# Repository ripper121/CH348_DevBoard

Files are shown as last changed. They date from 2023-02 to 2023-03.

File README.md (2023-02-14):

# CH348 DevBoard
### USB to Octal Serial / Uart ports

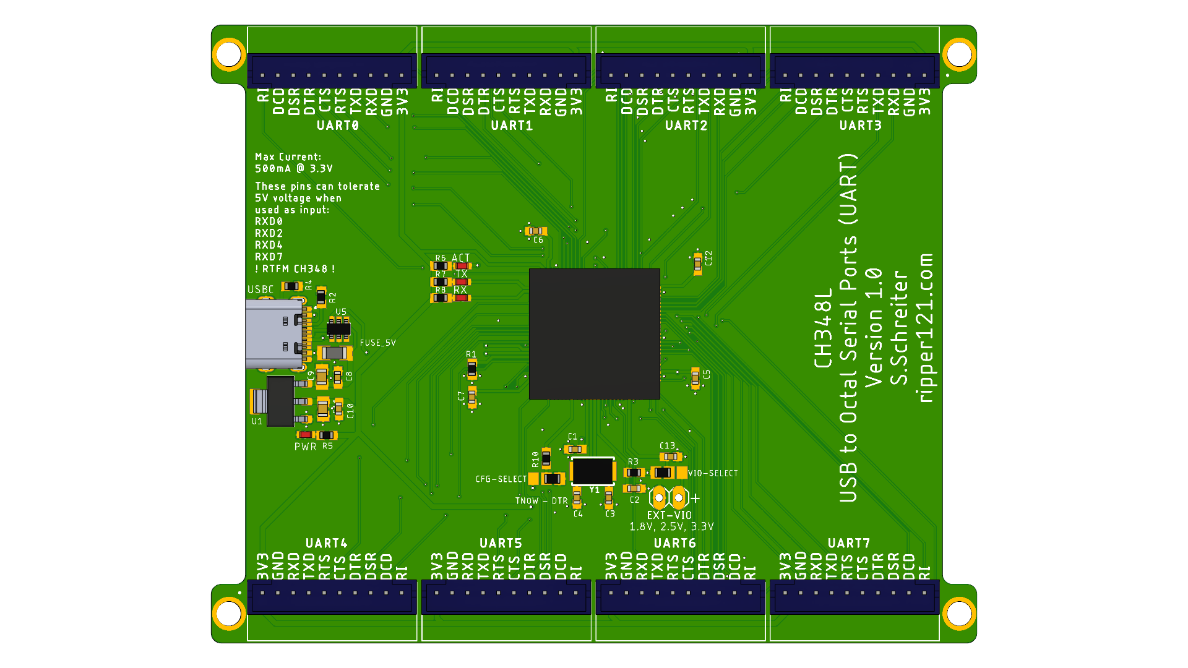
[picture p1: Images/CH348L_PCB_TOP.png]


### Features:
- No drivers needed for Winows and Linux
- USB-C Connector
- USB ESD Protection
- 500mA Polyfuse (self resettable fuse)
- Leds:
 - RX shows data receiving status
 - TX shows data transmitting status
 - ACT shows USB configuration completed status
- Jumpers
 - CFG: During power-on, if the CFG pin is
at a high level or not connected, all DTRx/ TNOWx pins
are configured to function as TNOW. CFG pin is low, all
DTRx/ TNOWx pins are configured for DTR function.
- VIO: The power supply of RTS0, CTS0, DTR4, DTR5, DTR6 and DTR7 pins of CH348L come from VCC,
these pins are 3.3V signal level. The power supply of other UARTs and MODEM signal pins come
from VIO, which are 3.3V/2.5V/1.8V matching VIO signal level.
- JST PH 2.0mm 10 Pin Connectors for the UART Pins
 - 3V3, GND, RXD, TXD, RTS, CTS, DTR, DSR, DCD, RI
- Size 100 x 80 mm
- 3.2 mm mounting holes

###### From Datasheet:
- 480Mbps high-speed USB device interface, peripheral components only need crystal oscillator and capacitors
- Built-in firmware, emulate standard UART interface, used to upgrade the original serial peripheral or expand additional UART via USB
- Original serial applications are totally compatible without any modification in Windows operating systems
- Hardware full duplex UART interface, integrated independent transmit-receive buffer, supports communication baud rate varies from 1200bps to 6Mbps
- UART supports 8 data bits, supports odd, even, and none parity, supports 1 or 2 stop bits
- Integrated the 2048-byte RX FIFO and 1024-byte TX FIFO for each UART
- Supports common MODEM signals RTS, DTR, DCD, RI, DSR and CTS
- Supports CTS and RTS hardware automatic flow control
- Supports half-duplex, provides sending status TNOW, used for controlling RS485 to transmit-receive switch
- Supports up to 48-channel GPIO input and output function
- Supports RS232/RS485/RS422 interface, through external voltage conversion chip
- Built-in EEPROM used to configure the chip of VID, PID, maximum current value, vendor and product information string, etc

[CH348 Datasheet](https://github.com/ripper121/CH348_DevBoard/raw/main/Datasheets/CH348DS1.PDF "CH348 Datasheet")

[Driver & Software](http://www.wch-ic.com/search?q=CH348&t=downloads "Driver & Software")

If you want to order one assembled PCB: [Contact Me](https://ripper121.com/contact/ "Contact Me")

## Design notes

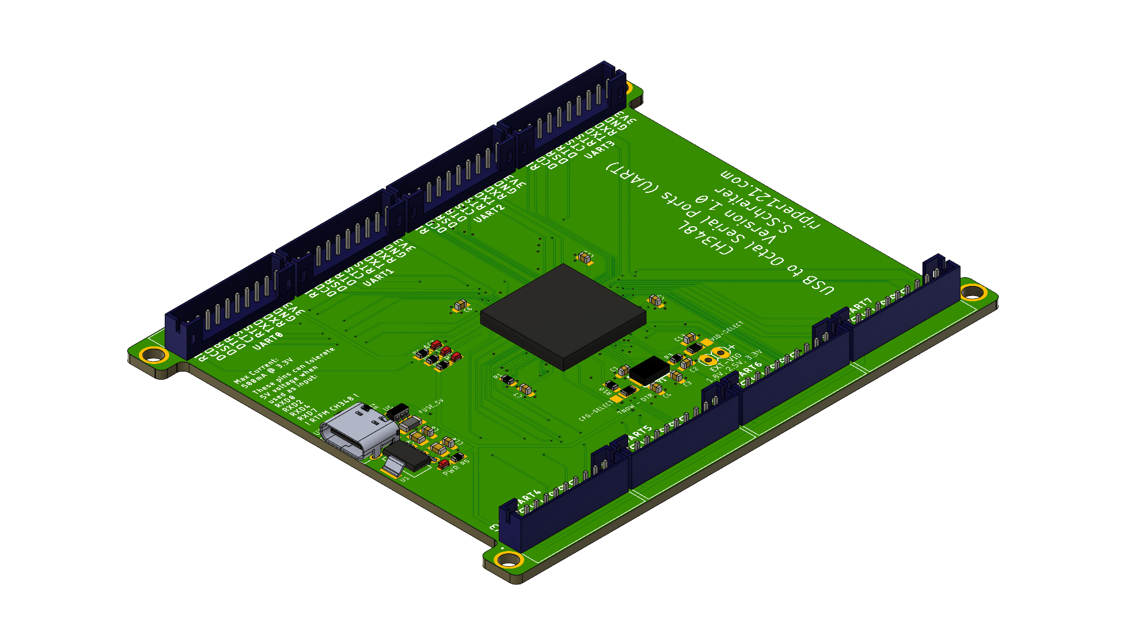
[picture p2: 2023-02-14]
Images/CH348L_PCB_ISO.png

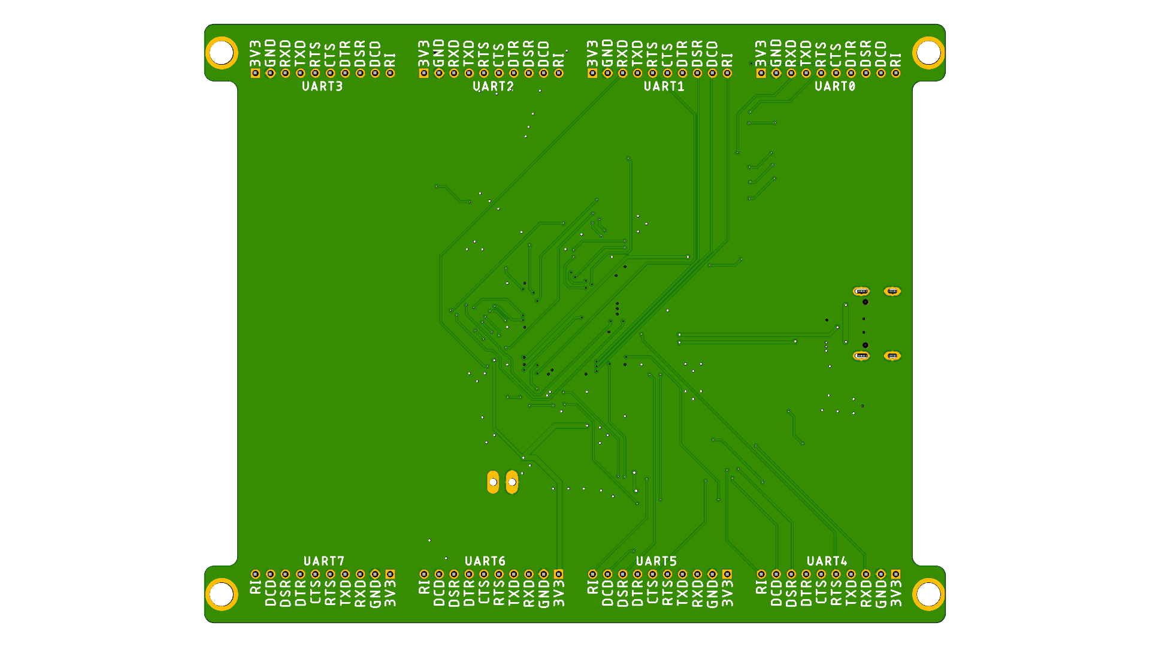
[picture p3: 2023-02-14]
Images/CH348L_PCB_BOTTOM.png

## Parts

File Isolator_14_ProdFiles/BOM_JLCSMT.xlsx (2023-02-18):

Comment | Designator | Footprint | JLCPCB Part #（optional）
100nF | C1, C2, C3, C4 | C0805
B10B-PH-K-S(LF)(SN) | IN | S10B-PH-K-S(LF)(SN)
π141M31 | U2 | SOIC-8
π142M31 | U1 | SOIC-8

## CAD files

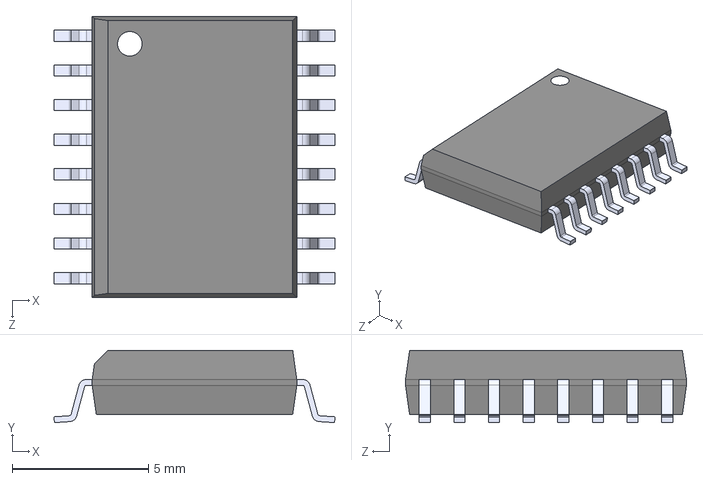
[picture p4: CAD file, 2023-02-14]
3D-Models/π140U30.STEP
10.3 x 2.65 x 10.3 mm

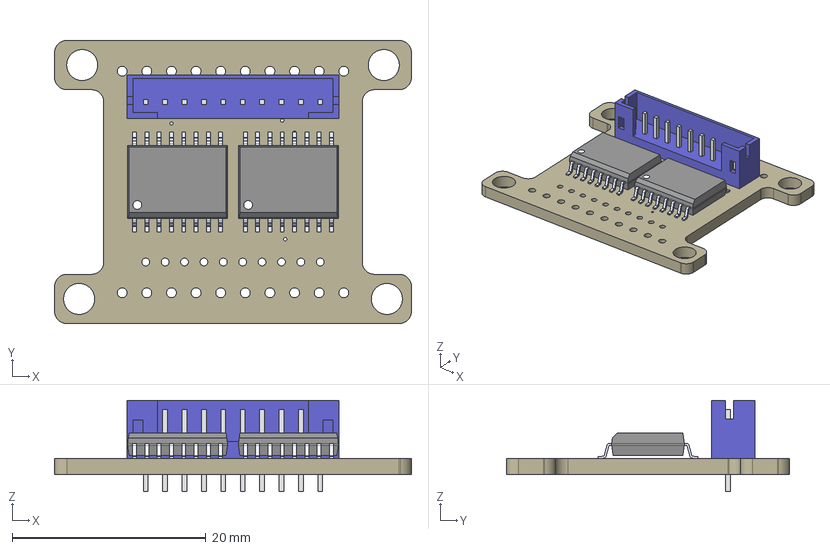
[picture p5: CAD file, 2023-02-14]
3D-Models/Isolator.step
36.8 x 29.2 x 9.40 mm
Board
SOIC-16
SOIC-16 (1)
JST_S10B-PH-K-S(LF)(SN)

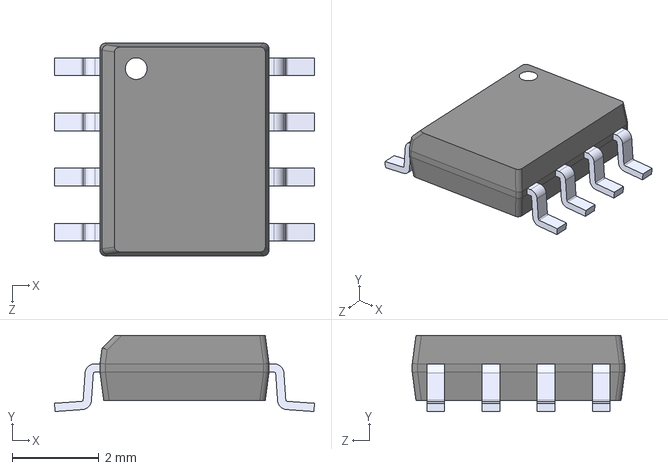
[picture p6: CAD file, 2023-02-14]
3D-Models/π120U30.STEP
5.99 x 1.75 x 4.90 mm

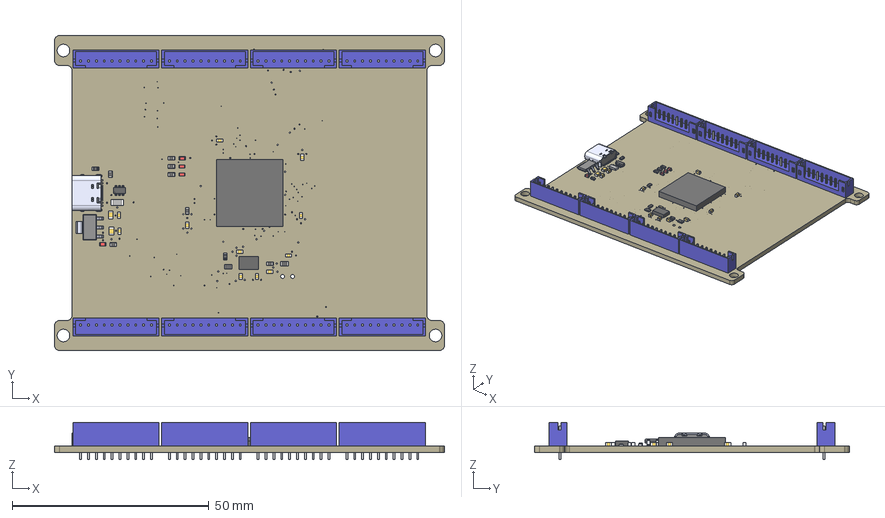
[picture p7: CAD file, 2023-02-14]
3D-Models/CH348L_DevBoard.step
99.1 x 80.0 x 9.40 mm
Board
LQFP100_14X14
SOT-23-6
TYPE-C-31-M-12
R1206
AMS1117-3.3_AMS1117-3.3.STEP
JST_S10B-PH-K-S(LF)(SN)
JST_S10B-PH-K-S(LF)(SN) (1)
JST_S10B-PH-K-S(LF)(SN) (2)
JST_S10B-PH-K-S(LF)(SN) (3)
JST_S10B-PH-K-S(LF)(SN) (4)
JST_S10B-PH-K-S(LF)(SN) (5)
JST_S10B-PH-K-S(LF)(SN) (6)
JST_S10B-PH-K-S(LF)(SN) (7)
2-SMD-5X3
A0R-JMP
A0R-JMP (1)
CHIP-LED0603 x 4
C0603 x 11
C0805 x 2
R0603 x 9

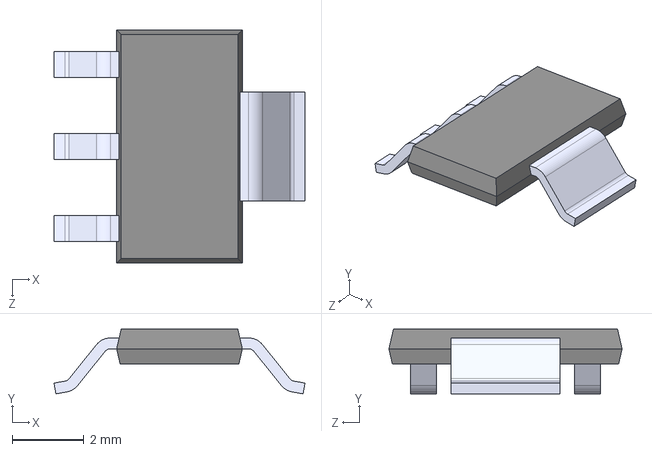
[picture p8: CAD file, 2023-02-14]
3D-Models/AMS1117-3.3.STEP
7.00 x 1.80 x 6.50 mm

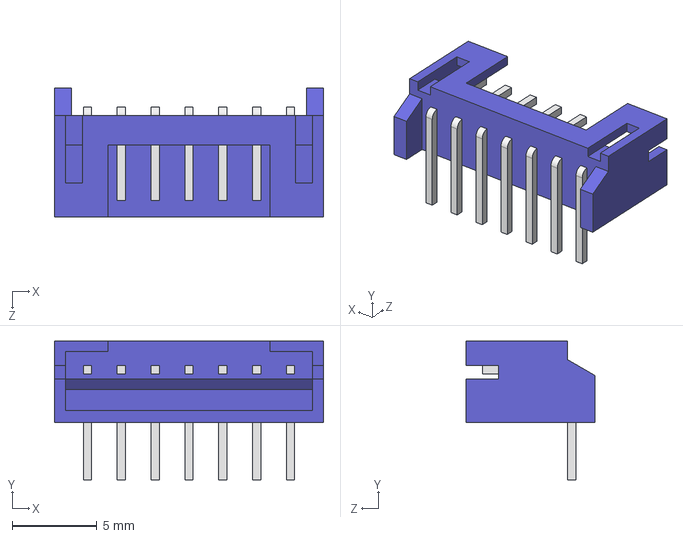
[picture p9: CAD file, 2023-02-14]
3D-Models/S7B-PH-K-S.STEP
15.9 x 8.20 x 7.60 mm

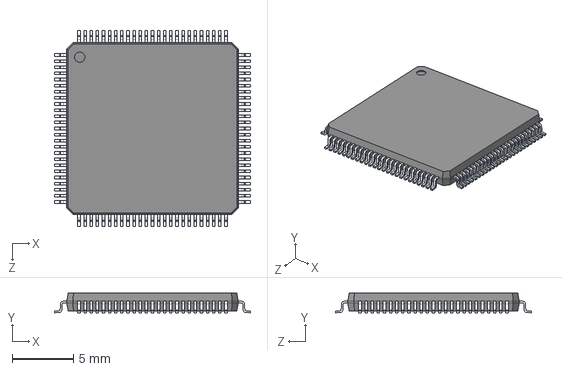
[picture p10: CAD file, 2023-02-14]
3D-Models/CH348L.STEP
16.0 x 1.60 x 16.0 mm

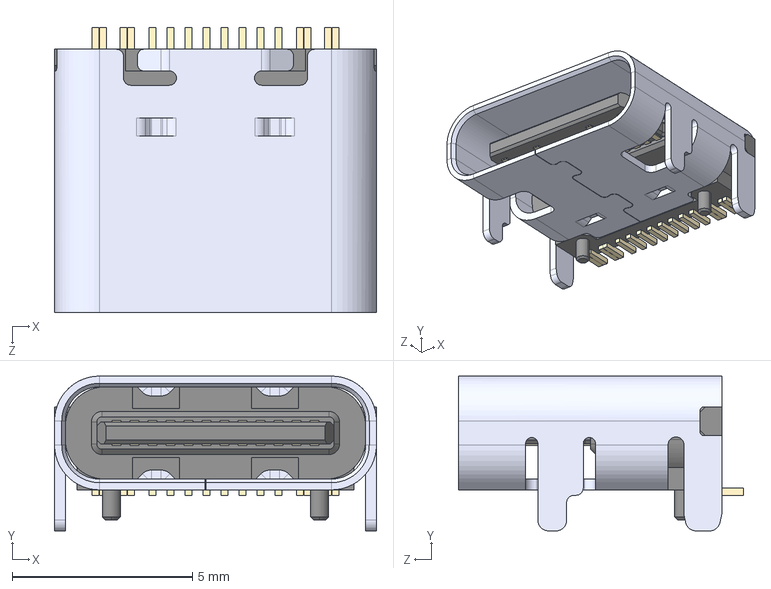
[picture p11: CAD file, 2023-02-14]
3D-Models/TYPE-C-31-M-12--3DModel-STEP-56544.STEP
8.94 x 4.30 x 7.90 mm

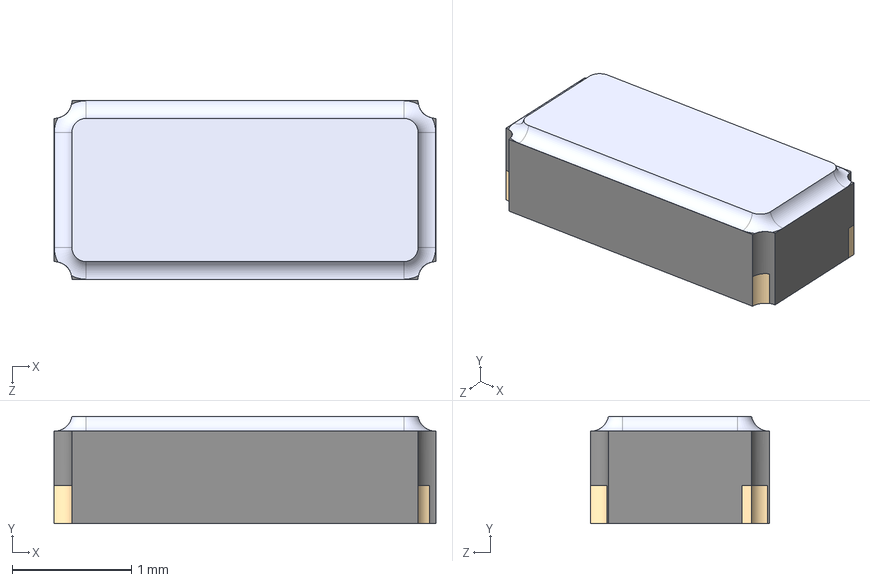
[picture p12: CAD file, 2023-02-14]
3D-Models/NX5032GA-8MHZ.STEP
3.20 x 0.9 x 1.50 mm

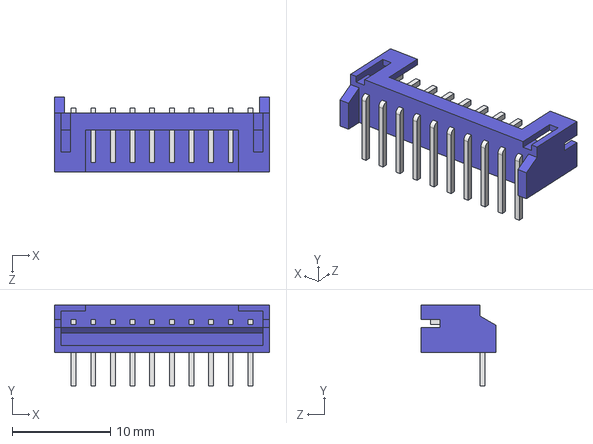
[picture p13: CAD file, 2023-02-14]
3D-Models/S10B-PH-K-S.STEP
21.9 x 8.20 x 7.60 mm

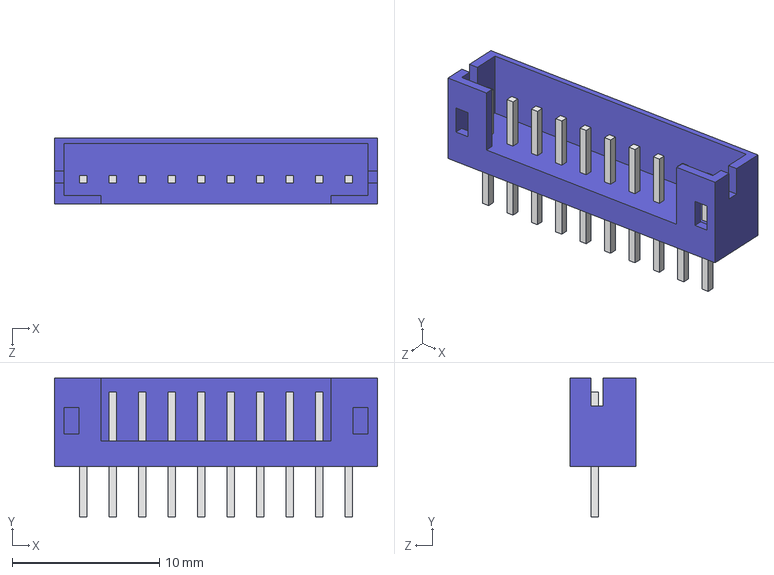
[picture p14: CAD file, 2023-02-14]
3D-Models/B10B-PH-K-S.STEP
21.9 x 9.40 x 4.50 mm

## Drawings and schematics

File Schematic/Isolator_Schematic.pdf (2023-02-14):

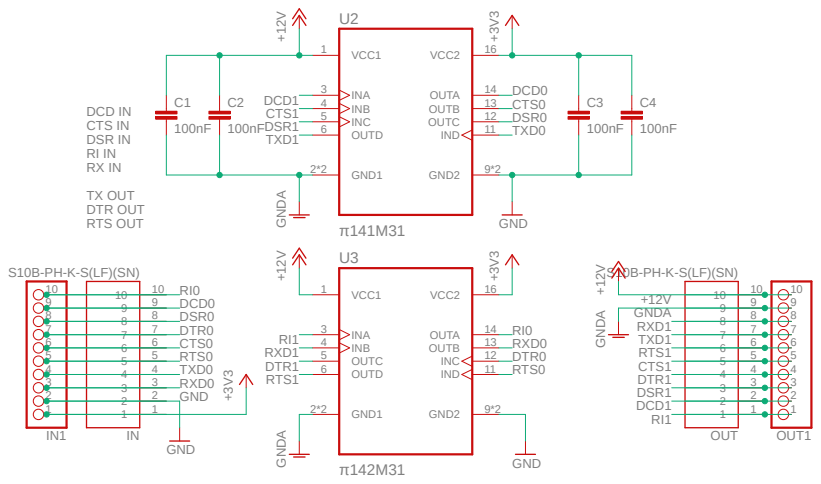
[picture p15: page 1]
DCD IN CTS IN DSR IN RI IN RX IN; TX OUT DTR OUT RTS OUT; +3V³ GNDA ⁺¹²V; GND; GNDA ⁺¹²V; +12V GNDA; GND +3V³; INA 3 INB 4 INC 5; IND; VCC1 1; VCC2; OUTA; OUTB; OUTC; OUTD 6; GND2; 9*2 GND1 2*2; INA 3 INB 4; INC; OUTC 5 OUTD 6; OUT; OUT1; RXD0; TXD0; RTS0; CTS0; DTR0; DSR0; DCD0; +12V GNDA RXD1; RXD1; TXD1; RTS1; CTS1; DTR1; DSR1; DCD1

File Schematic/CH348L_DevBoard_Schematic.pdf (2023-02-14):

# GND +5V +3V³

U1

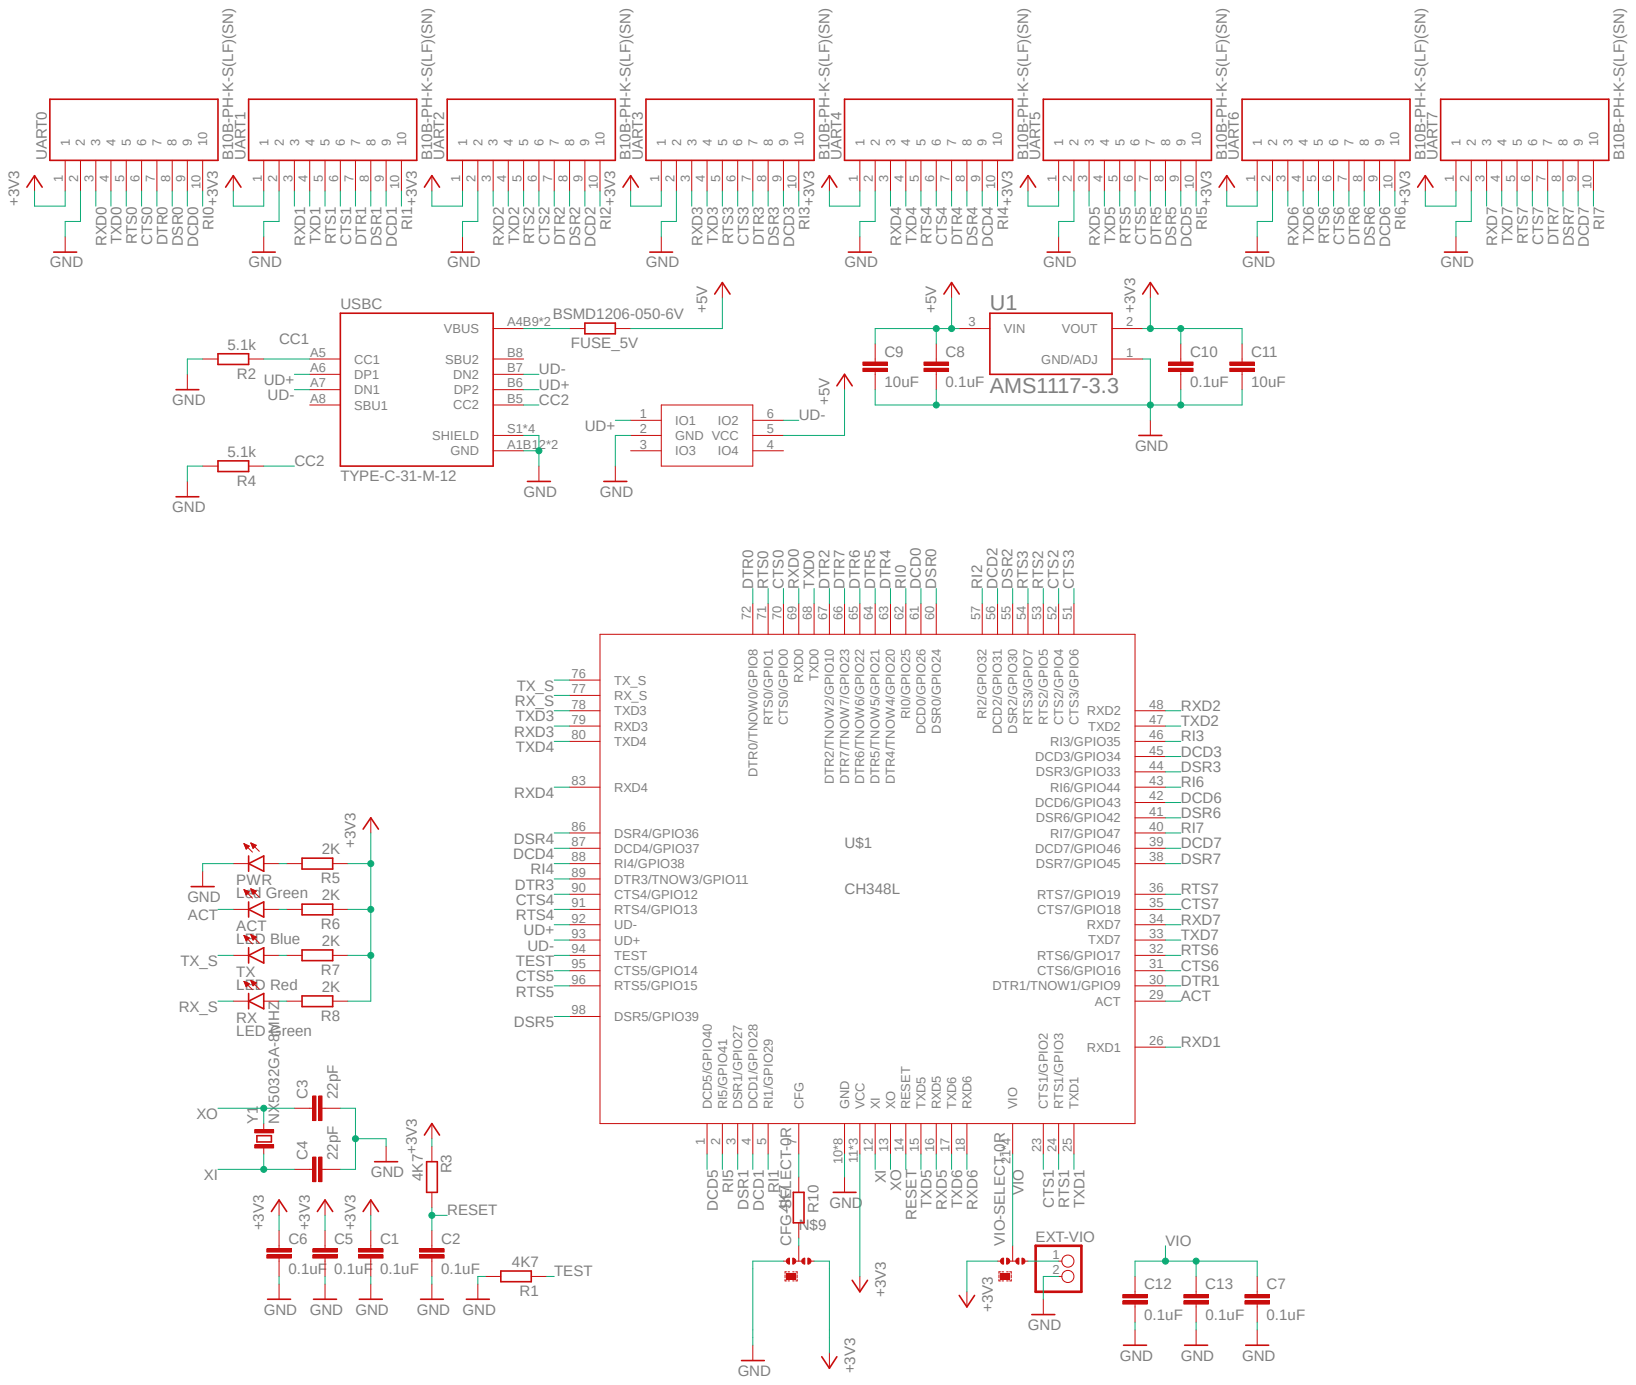
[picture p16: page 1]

GND B¹⁰B⁻PH⁻K⁻S⁽LF⁾⁽SN⁾ +3V³

7 GND 10*8 VCC 11*3 XI 12 XO 13 RESET 14 TXD5 15 RXD5 16 TXD6 17 RXD6 18 VIO 21*4 CTS1/GPIO2 23 RTS1/GPIO3 24 TXD1 25

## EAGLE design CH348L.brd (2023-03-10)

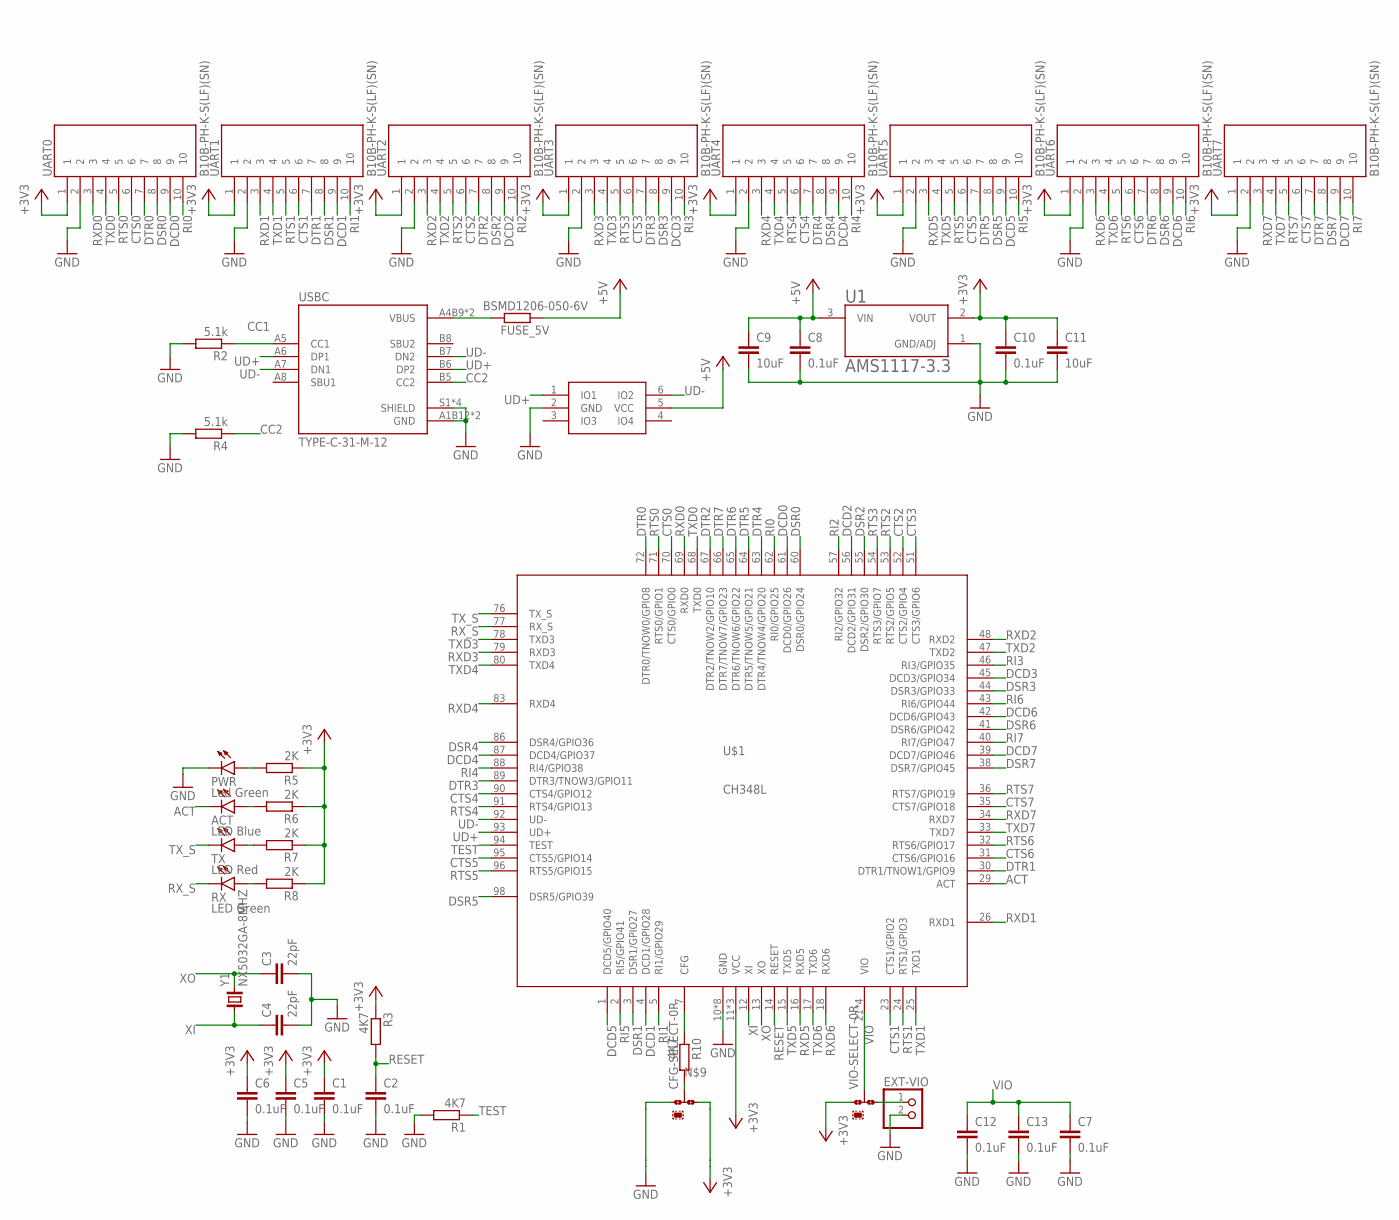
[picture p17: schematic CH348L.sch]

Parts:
ACT: LED Blue; CHIP-LED0603
C1, C2, C5, C6, C7, C8, C10, C12, C13: 0.1uF; C0603
C3, C4: 22pF; C0603
C9, C11: 10uF; C0805
CFG-SELECT: 0R-JUMPA; A0R-JMP
EXT-VIO: PINHD-1X2; 1X02
FUSE_5V: BSMD1206-050-6V; R1206
PWR: Led Green; CHIP-LED0603
R1, R3, R10: 4K7; R0603
R2, R4: 5.1k; R0603
R5, R6, R7, R8: 2K; R0603
RX: LED Green; CHIP-LED0603
TX: LED Red; CHIP-LED0603
U1: AMS1117-3.3; SOT229P700X180-4N
U5: ESDU5V0H4; SOT-23-6
U$1: CH348L; LQFP100_14X14
UART0, UART1, UART2, UART3, UART4, UART5, UART6, UART7: B10B-PH-K-S(LF)(SN); JST_S10B-PH-K-S(LF)(SN)
USBC: TYPE-C-31-M-12; HRO_TYPE-C-31-M-12
VIO-SELECT: 0R-JUMPA; A0R-JMP
Y1: NX5032GA-8MHZ; 2-SMD-5X3

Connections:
+3V3: C1.1, C5.1, C6.1, C10.1, C11.1, CFG-SELECT.3, R3.1, R5.1, R6.1, R7.1, R8.1, U1.2 (VOUT), U$1.11 (VCC), U$1.28 (VCC), U$1.75 (VCC), UART0.1, UART1.1, UART2.1, UART3.1, UART4.1, UART5.1, UART6.1, UART7.1, VIO-SELECT.1
+5V: C8.1, C9.1, FUSE_5V.1, U1.3 (VIN), U5.5 (VCC)
ACT: ACT.C, U$1.29 (ACT)
CC1: R2.1, USBC.A5 (CC1)
CC2: R4.1, USBC.B5 (CC2)
CFG: R10.1, U$1.7 (CFG)
CTS0: U$1.70 (CTS0/GPIO0), UART0.6
CTS1: U$1.23 (CTS1/GPIO2), UART1.6
CTS2: U$1.52 (CTS2/GPIO4), UART2.6
CTS3: U$1.51 (CTS3/GPIO6), UART3.6
CTS4: U$1.90 (CTS4/GPIO12), UART4.6
CTS5: U$1.95 (CTS5/GPIO14), UART5.6
CTS6: U$1.31 (CTS6/GPIO16), UART6.6
CTS7: U$1.35 (CTS7/GPIO18), UART7.6
DCD0: U$1.61 (DCD0/GPIO26), UART0.9
DCD1: U$1.4 (DCD1/GPIO28), UART1.9
DCD2: U$1.56 (DCD2/GPIO31), UART2.9
DCD3: U$1.45 (DCD3/GPIO34), UART3.9
DCD4: U$1.87 (DCD4/GPIO37), UART4.9
DCD5: U$1.1 (DCD5/GPIO40), UART5.9
DCD6: U$1.42 (DCD6/GPIO43), UART6.9
DCD7: U$1.39 (DCD7/GPIO46), UART7.9
DSR0: U$1.60 (DSR0/GPIO24), UART0.8
DSR1: U$1.3 (DSR1/GPIO27), UART1.8
DSR2: U$1.55 (DSR2/GPIO30), UART2.8
DSR3: U$1.44 (DSR3/GPIO33), UART3.8
DSR4: U$1.86 (DSR4/GPIO36), UART4.8
DSR5: U$1.98 (DSR5/GPIO39), UART5.8
DSR6: U$1.41 (DSR6/GPIO42), UART6.8
DSR7: U$1.38 (DSR7/GPIO45), UART7.8
DTR0: U$1.72 (DTR0/TNOW0/GPIO8), UART0.7
DTR1: U$1.30 (DTR1/TNOW1/GPIO9), UART1.7
DTR2: U$1.67 (DTR2/TNOW2/GPIO10), UART2.7
DTR3: U$1.89 (DTR3/TNOW3/GPIO11), UART3.7
DTR4: U$1.63 (DTR4/TNOW4/GPIO20), UART4.7
DTR5: U$1.64 (DTR5/TNOW5/GPIO21), UART5.7
DTR6: U$1.65 (DTR6/TNOW6/GPIO22), UART6.7
DTR7: U$1.66 (DTR7/TNOW7/GPIO23), UART7.7
GND: C1.2, C2.2, C3.2, C4.2, C5.2, C6.2, C7.2, C8.2, C9.2, C10.2, C11.2, C12.2, C13.2, CFG-SELECT.1, EXT-VIO.2, PWR.C, R1.2, R2.2, R4.2, U1.1 (GND/ADJ), U5.2 (GND), U$1.10 (GND), U$1.19 (GND), U$1.20 (GND), U$1.27 (GND), U$1.37 (GND), U$1.49 (GND), U$1.74 (GND), U$1.99 (GND), UART0.2, UART1.2, UART2.2, UART3.2, UART4.2, UART5.2, UART6.2, UART7.2, USBC.A1B12 (GND), USBC.B1A12 (GND), USBC.S1 (SHIELD), USBC.S2 (SHIELD), USBC.S3 (SHIELD), USBC.S4 (SHIELD)
unnamed: PWR.A, R5.2
unnamed: FUSE_5V.2, USBC.A4B9 (VBUS), USBC.B4A9 (VBUS)
unnamed: ACT.A, R6.2
unnamed: R7.2, TX.A
unnamed: R8.2, RX.A
unnamed: EXT-VIO.1, VIO-SELECT.3
unnamed: CFG-SELECT.2, R10.2
RESET: C2.1, R3.2, U$1.14 (RESET)
RI0: U$1.62 (RI0/GPIO25), UART0.10
RI1: U$1.5 (RI1/GPIO29), UART1.10
RI2: U$1.57 (RI2/GPIO32), UART2.10
RI3: U$1.46 (RI3/GPIO35), UART3.10
RI4: U$1.88 (RI4/GPIO38), UART4.10
RI5: U$1.2 (RI5/GPIO41), UART5.10
RI6: U$1.43 (RI6/GPIO44), UART6.10
RI7: U$1.40 (RI7/GPIO47), UART7.10
RTS0: U$1.71 (RTS0/GPIO1), UART0.5
RTS1: U$1.24 (RTS1/GPIO3), UART1.5
RTS2: U$1.53 (RTS2/GPIO5), UART2.5
RTS3: U$1.54 (RTS3/GPIO7), UART3.5
RTS4: U$1.91 (RTS4/GPIO13), UART4.5
RTS5: U$1.96 (RTS5/GPIO15), UART5.5
RTS6: U$1.32 (RTS6/GPIO17), UART6.5
RTS7: U$1.36 (RTS7/GPIO19), UART7.5
RXD0: U$1.69 (RXD0), UART0.3
RXD1: U$1.26 (RXD1), UART1.3
RXD2: U$1.48 (RXD2), UART2.3
RXD3: U$1.79 (RXD3), UART3.3
RXD4: U$1.83 (RXD4), UART4.3
RXD5: U$1.16 (RXD5), UART5.3
RXD6: U$1.18 (RXD6), UART6.3
RXD7: U$1.34 (RXD7), UART7.3
RX_S: RX.C, U$1.77 (RX_S)
TEST: R1.1, U$1.94 (TEST)
TXD0: U$1.68 (TXD0), UART0.4
TXD1: U$1.25 (TXD1), UART1.4
TXD2: U$1.47 (TXD2), UART2.4
TXD3: U$1.78 (TXD3), UART3.4
TXD4: U$1.80 (TXD4), UART4.4
TXD5: U$1.15 (TXD5), UART5.4
TXD6: U$1.17 (TXD6), UART6.4
TXD7: U$1.33 (TXD7), UART7.4
TX_S: TX.C, U$1.76 (TX_S)
UD+: U5.1 (IO1), U$1.93 (UD+), USBC.A6 (DP1), USBC.B6 (DP2)
UD-: U5.6 (IO2), U$1.92 (UD-), USBC.A7 (DN1), USBC.B7 (DN2)
VIO: C7.1, C12.1, C13.1, U$1.21 (VIO), U$1.22 (VIO), U$1.50 (VIO), U$1.100 (VIO), VIO-SELECT.2
XI: C4.1, U$1.12 (XI), Y1.1
XO: C3.1, U$1.13 (XO), Y1.2

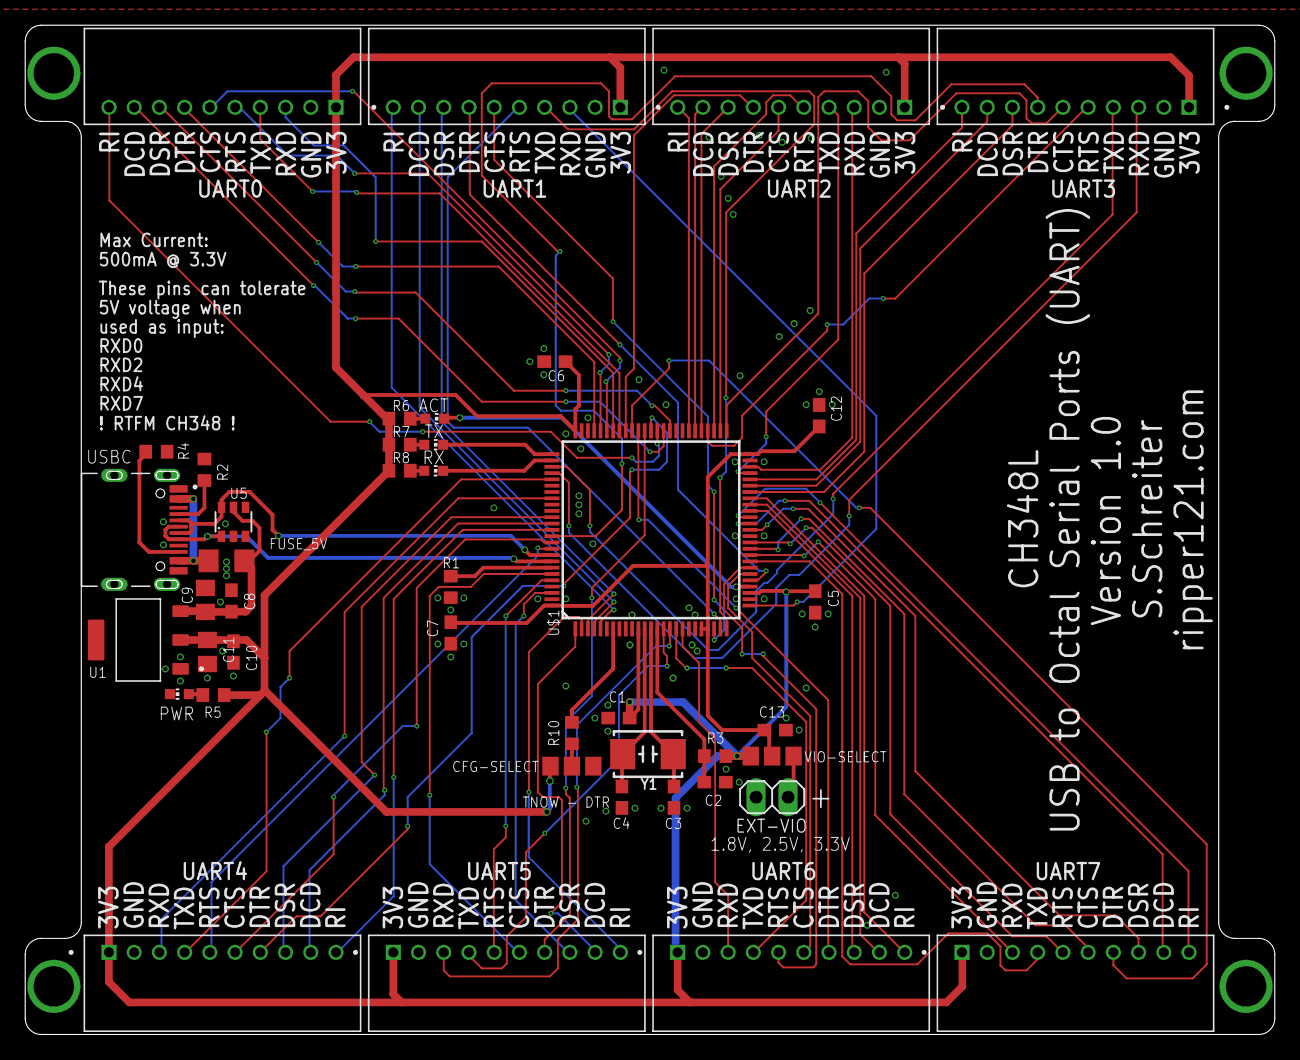
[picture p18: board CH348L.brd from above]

Board: 2 copper layers, 99.1 x 80.0 mm, 43 parts (0 on the bottom side), 87 nets.

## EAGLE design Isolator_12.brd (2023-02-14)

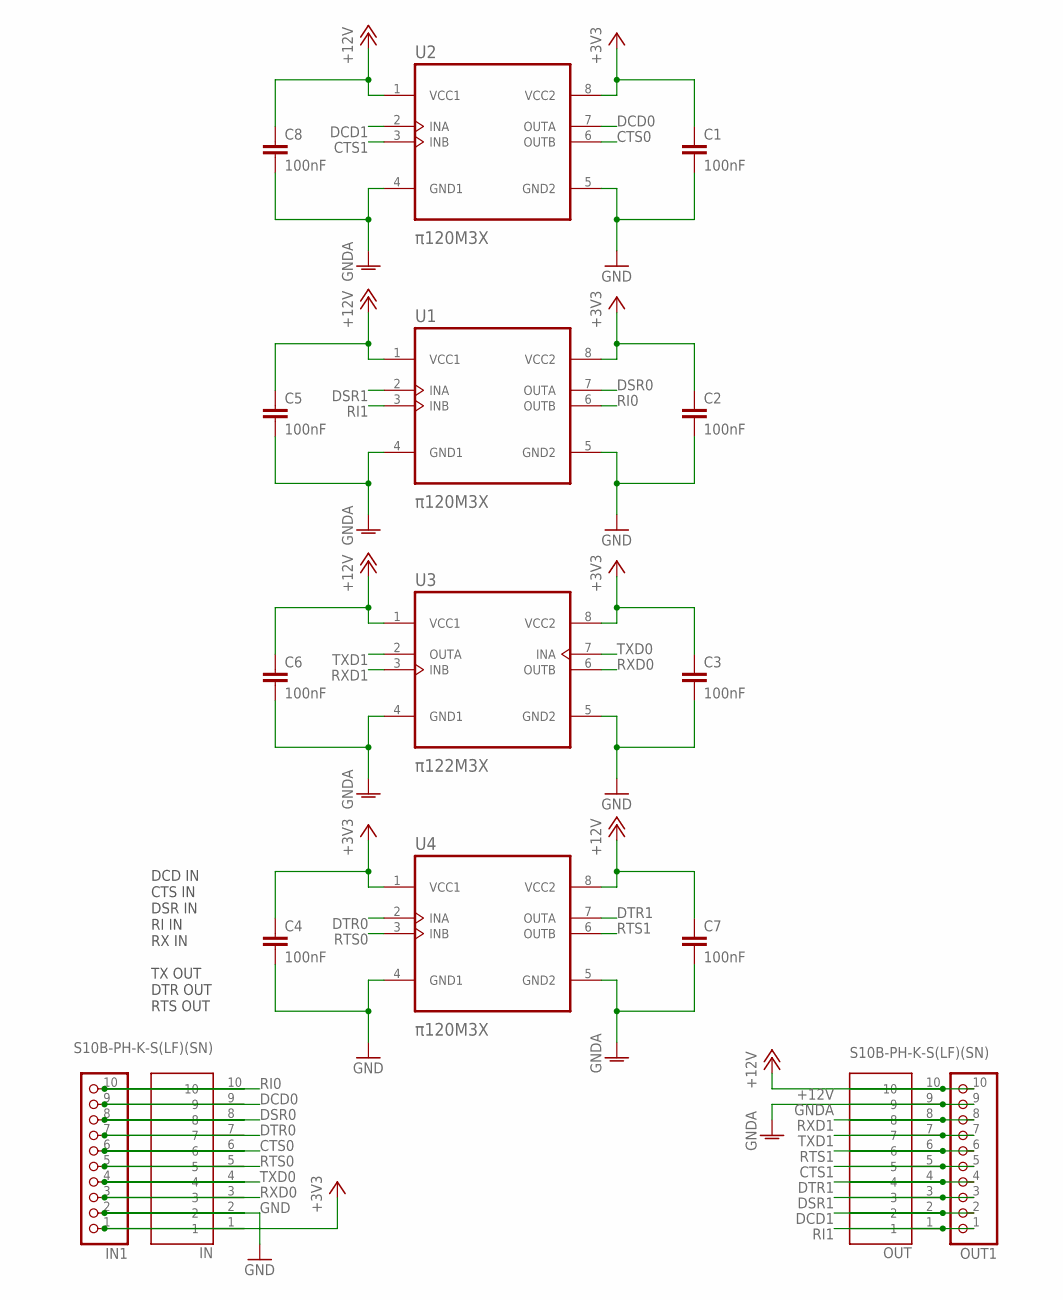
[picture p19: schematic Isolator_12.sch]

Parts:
C1, C2, C3, C4, C5, C6, C7, C8: 100nF; C0805
IN: S10B-PH-K-S(LF)(SN); JST_S10B-PH-K-S(LF)(SN)
IN1: PINHD-1X10; 1X10
OUT: S10B-PH-K-S(LF)(SN); JST_S10B-PH-K-S(LF)(SN)
OUT1: PINHD-1X10; 1X10
U1, U2, U4: π120M3X; SOIC-8
U3: π122M3X; SOIC-8

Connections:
+3V3: C1.1, C2.1, C3.1, C4.1, IN.1, IN1.1, U1.8 (VCC2), U2.8 (VCC2), U3.8 (VCC2), U4.1 (VCC1)
+12V: C5.1, C6.1, C7.1, C8.1, OUT.10, OUT1.10, U1.1 (VCC1), U2.1 (VCC1), U3.1 (VCC1), U4.8 (VCC2)
CTS0: IN.6, IN1.6, U2.6 (OUTB)
CTS1: OUT.5, OUT1.5, U2.3 (INB)
DCD0: IN.9, IN1.9, U2.7 (OUTA)
DCD1: OUT.2, OUT1.2, U2.2 (INA)
DSR0: IN.8, IN1.8, U1.7 (OUTA)
DSR1: OUT.3, OUT1.3, U1.2 (INA)
DTR0: IN.7, IN1.7, U4.2 (INA)
DTR1: OUT.4, OUT1.4, U4.7 (OUTA)
GND: C1.2, C2.2, C3.2, C4.2, IN.2, IN1.2, U1.5 (GND2), U2.5 (GND2), U3.5 (GND2), U4.4 (GND1)
GNDA: C5.2, C6.2, C7.2, C8.2, OUT.9, OUT1.9, U1.4 (GND1), U2.4 (GND1), U3.4 (GND1), U4.5 (GND2)
RI0: IN.10, IN1.10, U1.6 (OUTB)
RI1: OUT.1, OUT1.1, U1.3 (INB)
RTS0: IN.5, IN1.5, U4.3 (INB)
RTS1: OUT.6, OUT1.6, U4.6 (OUTB)
RXD0: IN.3, IN1.3, U3.6 (OUTB)
RXD1: OUT.8, OUT1.8, U3.3 (INB)
TXD0: IN.4, IN1.4, U3.7 (INA)
TXD1: OUT.7, OUT1.7, U3.2 (OUTA)

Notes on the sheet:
DCD IN CTS IN DSR IN RI IN RX IN TX OUT DTR OUT RTS OUT

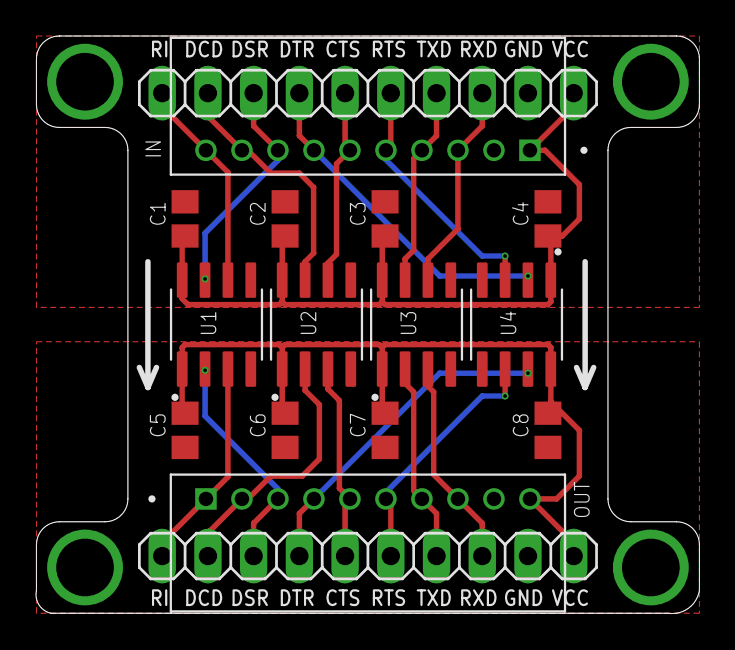
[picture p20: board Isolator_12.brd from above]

Board: 2 copper layers, 36.9 x 32.1 mm, 16 parts (0 on the bottom side), 20 nets.

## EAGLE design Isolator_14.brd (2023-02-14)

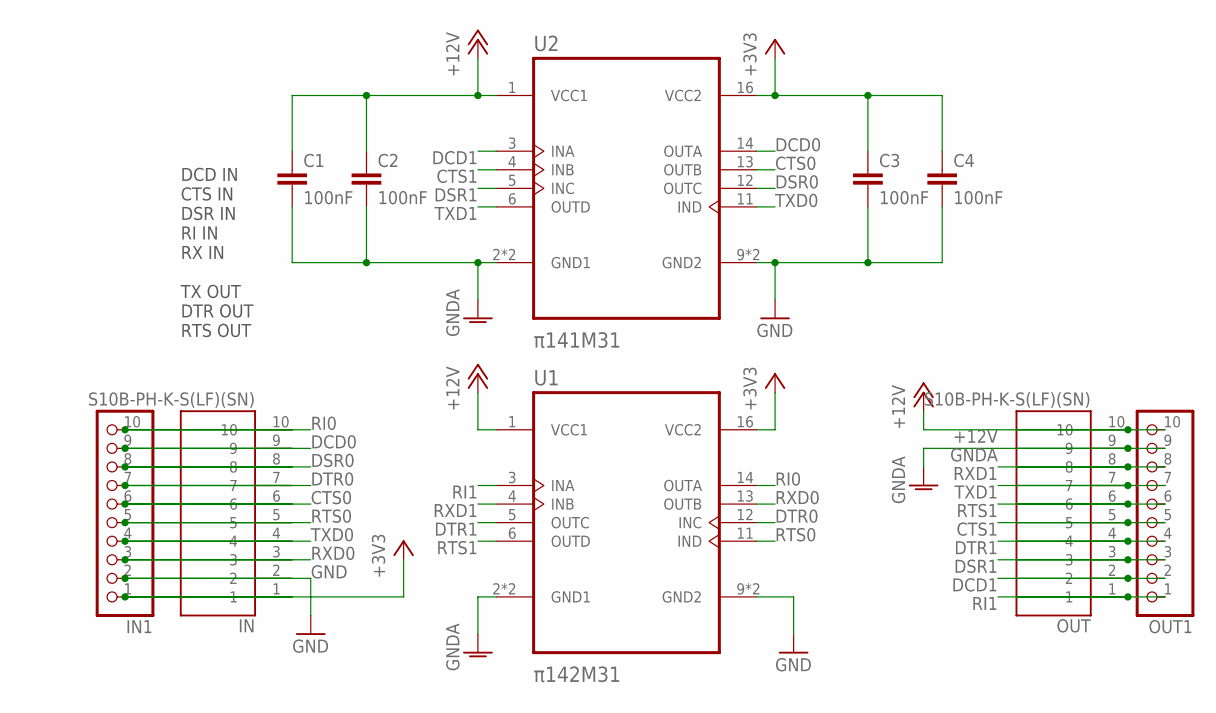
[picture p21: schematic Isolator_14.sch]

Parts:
C1, C2, C3, C4: 100nF; C0805
IN: S10B-PH-K-S(LF)(SN); JST_S10B-PH-K-S(LF)(SN)
IN1: PINHD-1X10; 1X10
OUT: S10B-PH-K-S(LF)(SN); JST_S10B-PH-K-S(LF)(SN)
OUT1: PINHD-1X10; 1X10
U1: π142M31; SOIC-16
U2: π141M31; SOIC-16

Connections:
+3V3: C3.1, C4.1, IN.1, IN1.1, U1.16 (VCC2), U2.16 (VCC2)
+12V: C1.1, C2.1, OUT.10, OUT1.10, U1.1 (VCC1), U2.1 (VCC1)
CTS0: IN.6, IN1.6, U2.13 (OUTB)
CTS1: OUT.5, OUT1.5, U2.4 (INB)
DCD0: IN.9, IN1.9, U2.14 (OUTA)
DCD1: OUT.2, OUT1.2, U2.3 (INA)
DSR0: IN.8, IN1.8, U2.12 (OUTC)
DSR1: OUT.3, OUT1.3, U2.5 (INC)
DTR0: IN.7, IN1.7, U1.12 (INC)
DTR1: OUT.4, OUT1.4, U1.5 (OUTC)
GND: C3.2, C4.2, IN.2, IN1.2, U1.9 (GND2), U1.15 (GND2), U2.9 (GND2), U2.15 (GND2)
GNDA: C1.2, C2.2, OUT.9, OUT1.9, U1.2 (GND1), U1.8 (GND1), U2.2 (GND1), U2.8 (GND1)
RI0: IN.10, IN1.10, U1.14 (OUTA)
RI1: OUT.1, OUT1.1, U1.3 (INA)
RTS0: IN.5, IN1.5, U1.11 (IND)
RTS1: OUT.6, OUT1.6, U1.6 (OUTD)
RXD0: IN.3, IN1.3, U1.13 (OUTB)
RXD1: OUT.8, OUT1.8, U1.4 (INB)
TXD0: IN.4, IN1.4, U2.11 (IND)
TXD1: OUT.7, OUT1.7, U2.6 (OUTD)

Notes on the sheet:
DCD IN CTS IN DSR IN RI IN RX IN TX OUT DTR OUT RTS OUT

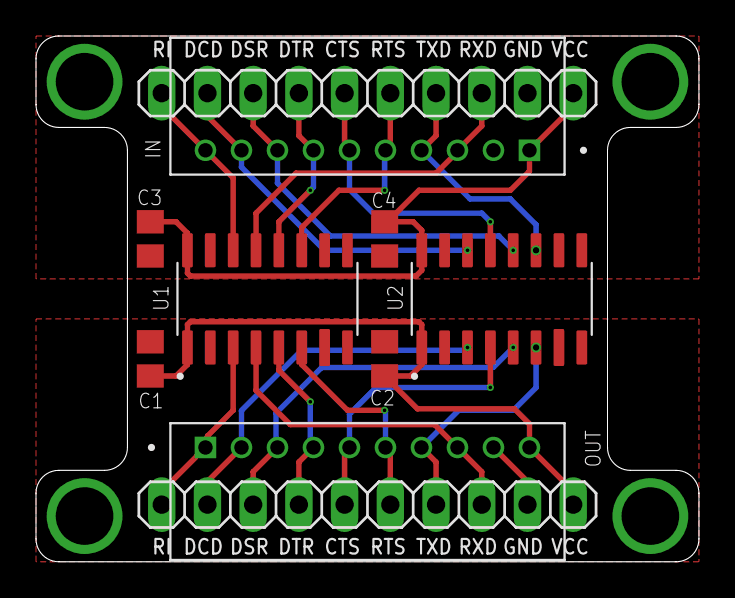
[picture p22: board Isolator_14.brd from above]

Board: 2 copper layers, 36.8 x 29.2 mm, 10 parts (0 on the bottom side), 20 nets.

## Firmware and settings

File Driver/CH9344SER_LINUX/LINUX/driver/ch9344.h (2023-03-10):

#ifndef _CH9344_H
#define _CH9344_H

/*
 * Baud rate and default timeout
 */
#define DEFAULT_BAUD_RATE    9600
#define DEFAULT_TIMEOUT      2000
#define DEFAULT_CLOSETIMEOUT 100

/*
 * CMSPAR, some architectures can't have space and mark parity.
 */

#ifndef CMSPAR
#define CMSPAR 0
#endif

/*
 * Major and minor numbers.
 */

#define CH9344_TTY_MAJOR  168
#define CH9344_TTY_MINORS 256

#define USB_MINOR_BASE 192

#define CH9344_CTO_D  0x01
#define CH9344_CTO_R  0x02
#define CH9344_CTI_C  0x01
#define CH9344_CTI_DS 0x02
#define CH9344_CTI_R  0x04
#define CH9344_CTI_DC 0x08

#define CH9344_LO 0x10
#define CH9344_LP 0x20
#define CH9344_LF 0x40
#define CH9344_LB 0x80

#define CMD_W_R  0xC0
#define CMD_W_BR 0x80
#define CMD_S_T  0x20

#define CMD_WB_E 0x90
#define CMD_RB_E 0xC0

#define M_NOR 0x00
#define M_RS  0x01
#define M_IO  0x02
#define M_HF  0x03

#define G_DO 0x01
#define G_DI 0x00

#define R_MOD  0x97
#define R_IO_D 0x98
#define R_IO_O 0x99
#define R_IO_I 0x9b
#define R_TM_O 0x9c
#define R_INIT 0xA1

#define R_IO_CE 0xA3
#define R_IO_CD 0xA4
#define R_IO_CO 0xA5
#define R_IO_CI 0xA7
#define R_IO_RE 0xAA
#define R_IO_RD 0xAB

#define R_C1 0x01
#define R_C2 0x02
#define R_C3 0x03
#define R_C4 0x04
#define R_C5 0x06

#define R_II_B1 0x06
#define R_II_B2 0x02
#define R_II_B3 0x00

#define CMD_VER 0x96

/*
 * Internal driver structures.
 */

#define CH9344_NW 4
#define CH9344_NR 32

#define NUMSTEP 8
#define MAXGPIO 48
#define MAXPORT 8

#define IO_H 1
#define IO_L 0

struct ch9344_wb {
    unsigned char *buf;
    dma_addr_t dmah;
    int len;
    int use;
    struct urb *urb;
    struct ch9344 *instance;
    int portnum;
};

struct ch9344_rb {
    int size;
    unsigned char *base;
    dma_addr_t dma;
    int index;
    struct ch9344 *instance;
};

struct usb_ch9344_line_coding {
    __le32 dwDTERate;
    __u8 bCharFormat;
#define SB1   0
#define SB1_5 1
#define SB2   2

    __u8 bParityType;
#define PAN 0
#define PAO 1
#define PAE 2
#define PAM 3
#define PAS 4

    __u8 bDataBits;
} __attribute__((packed));

struct ch9344_ttyport {
    struct tty_port port;
    int portnum;
    void *portdata;
    bool write_empty;
    struct usb_ch9344_line_coding line; /* bits, stop, parity */
    unsigned int ctrlin;                /* input control lines (DCD, DSR, RI, break, overruns) */
    unsigned int ctrlout;               /* output control lines (DTR, RTS) */
    struct async_icount iocount;        /* counters for control line changes */
    struct async_icount oldcount;       /* for comparison of counter */
    u8 uartmode;                        /* uart mode */
    unsigned char clocal;               /* termios CLOCAL */
    wait_queue_head_t wioctl;           /* for write */
    wait_queue_head_t wmodemioctl;      /* for ioctl */
    bool isopen;
    struct work_struct work; /* work queue entry for line discipline waking up */
};

typedef enum {
    CHIP_CH9344 = 0,
    CHIP_CH348L = 1,
    CHIP_CH348Q = 2,
} CHIPTYPE;

struct ch9344 {
    struct usb_device *dev;        /* the corresponding usb device */
    struct usb_interface *control; /* control interface */
    struct usb_interface *data;    /* data interface */
    unsigned int num_ports;
    bool modeline9;
    struct ch9344_ttyport ttyport[MAXPORT]; /* our tty port data */
    CHIPTYPE chiptype;
    int port_offset;

    struct urb *cmdreadurb; /* urbs */
    u8 *cmdread_buffer;     /* buffers of urbs */
    dma_addr_t cmdread_dma; /* dma handles of buffers */

    int opencounts;
    struct ch9344_wb wb[MAXPORT][CH9344_NW];
    unsigned long read_urbs_free;
    struct urb *read_urbs[CH9344_NR];
    struct ch9344_rb read_buffers[CH9344_NR];
    struct ch9344_wb *putbuffer; /* for ch9344_tty_put_char() */
    int rx_buflimit;
    int rx_endpoint;
    int tx_endpoint;
    int cmdtx_endpoint;
    int cmdrx_endpoint;
    int ctrl_endpoint;

    spinlock_t read_lock;
    int write_used; /* number of non-empty write buffers */
    int transmitting;
    spinlock_t write_lock;
    struct mutex mutex;
    bool disconnected;
    u64 gpioenables;
    u64 gpiodirs;
    u64 gpiovals;
    u64 gpiovalins;
    u8 gpiodir[MAXGPIO];          /* gpio direction */
    u8 gpioval[MAXGPIO];          /* gpio output value */
    u16 gpiovalin;                /* gpio input value */
    bool gpio_recv;               /* gpio input sync flag */
    wait_queue_head_t wgpioioctl; /* for gpio input ioctl */
    struct mutex gpiomutex;
    unsigned int writesize;         /* max packet size for the output bulk endpoint */
    unsigned int readsize, cmdsize; /* buffer sizes for freeing */
    unsigned int ctrlsize;
    unsigned int minor;      /* ch9344 minor number */
    unsigned int susp_count; /* number of suspended interfaces */
    u8 bInterval;
    struct usb_anchor delayed; /* writes queued for a device about to be woken */
    unsigned long quirks;
    struct kref kref;
};

/* constants describing various quirks and errors */
#define SINGLE_RX_URB            BIT(1)
#define NO_DATA_INTERFACE        BIT(4)
#define IGNORE_DEVICE            BIT(5)
#define QUIRK_CONTROL_LINE_STATE BIT(6)
#define CLEAR_HALT_CONDITIONS    BIT(7)

#endif

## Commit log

2023-02-18 GPIO Header, ESD
    [BOM_JLCSMT.xlsx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]
2023-03-10 Fixed UD+ UD- swap
    [CH348L.brd, CH348L.sch]
2023-03-10 Driver & Tools
